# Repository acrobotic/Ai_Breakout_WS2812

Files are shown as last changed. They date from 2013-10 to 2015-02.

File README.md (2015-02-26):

Overview
---
This repository includes the Eagle design files (schematics and layout) for our [WS2812 Breakout Board][1]. The WS2812 is a 
Smart RGB LED with an embedded LED driver (WS2811) that needs only one data input line for controlling brightness and color. 
It represents the most compact solution for adding an RGB LED to a Microcontroller-powered project.

Example firmware files are included in this repository as well.

Product page
---
Please consider buying products from Acrobotic to help fund future Open-Source projects like this! We'll always put our best effort in every project, and release all our design files and code for you to use.

[Tutorials, technical details, and more information about this product can be found here: http://acrobotic.com/catalog/product/view/id/44][1]

License Information
---

All contents of this repository are licensed under a [Creative Commons Attribution-ShareAlike 3.0 Unported License](http://creativecommons.org/licenses/by-sa/3.0/).



[1]: http://acrobotic.com/catalog/product/view/id/44 "WS2812 Breakout Board"

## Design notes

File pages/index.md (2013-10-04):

---
layout: page
title: Ai Breakout WS2812
tagline: Board design files and example firmware for a WS2812 breakout board.
github_project: Ai_Breakout_WS2812
github_user_url: https://github.com/acrobotic
---
{% include JB/setup %}
{% include INCLUDE.md %}

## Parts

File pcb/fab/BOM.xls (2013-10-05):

Ai Breakout WS2812 – BOM
Cisco Zabala (x1sc0@acrobotic.com) last updated: 05.10.2013
Manufacturer | Manuf. Part Number | Vendor | Vendor Part Number | Type | Designator | Qty | Description | Case | SMD, BGA, LCC, OR TH | Notes
TDK |  | Digi-Key | 445-1324-1-ND | Capacitors | C1 | 1 | CAP CER 0.1UF 50V Y5V 0603 | 0603 | SMD
WorldSemi | WS2812 | Acrobotic | LED-00003 | LEDs | RGB | 1 | Intelligent control LED | SMD | SMD

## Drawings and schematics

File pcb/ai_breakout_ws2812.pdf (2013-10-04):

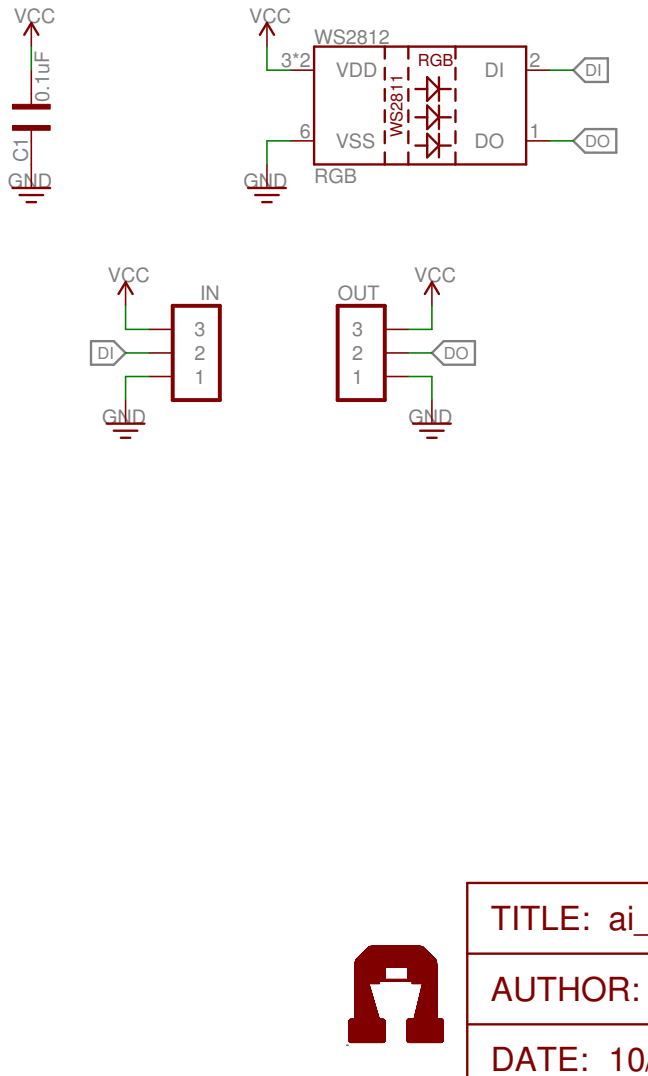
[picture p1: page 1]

AUTHOR: A.I. HARDWARE SITH LORDS | REV: 1.1
DATE: 10/4/13 1:54 PM | SHEET: 1/1

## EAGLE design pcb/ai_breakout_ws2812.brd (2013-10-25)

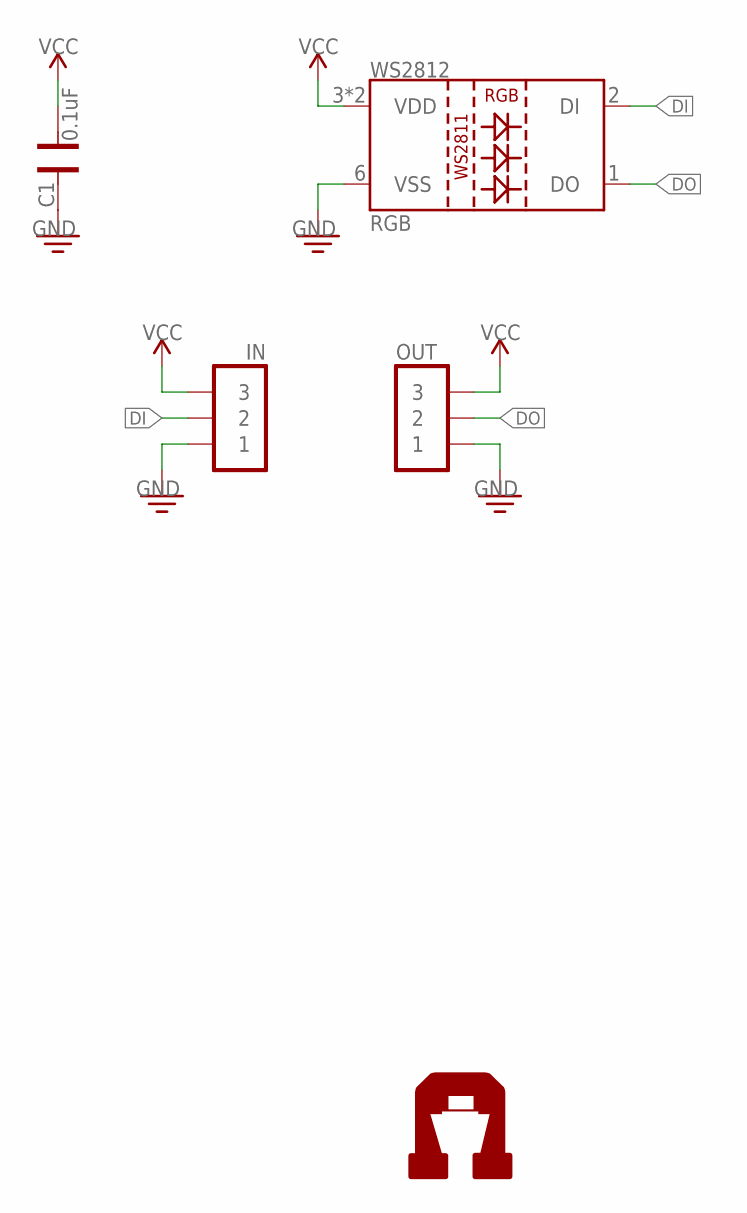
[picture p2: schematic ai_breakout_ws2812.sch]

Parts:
C1: 0.1uF; CAP-0603
IN: 1X03
OUT: 1X03
RGB: LED-WS2812
U$5: AI-LOGOL; AI-LOGO-L

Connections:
DI: IN.2, RGB.2 (DI)
DO: OUT.2, RGB.1 (DO)
GND: C1.2, IN.1, OUT.1, RGB.6 (VSS)
VCC: C1.1, IN.3, OUT.3, RGB.3 (VDD), RGB.5 (VDD)

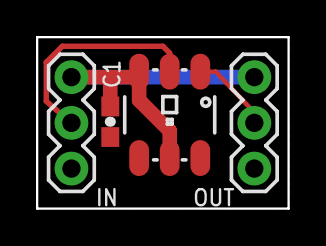
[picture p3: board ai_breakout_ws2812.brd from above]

Board: 2 copper layers, 14.0 x 9.5 mm, 5 parts (1 on the bottom side), 4 nets.

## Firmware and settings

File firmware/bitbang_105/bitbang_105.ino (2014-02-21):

/*------------------------------------------------------------------------
  Acrobotic - 01/10/2013
  Author: x1sc0 
  Platforms: Arduino Uno R3
  File: bitbang_105.ino

  Description: 
  This code sample accompanies the "How To Control 'Smart' RGB LEDs: 
  WS2811, WS2812, and WS2812B (Bitbanging Tutorial)" Instructable 
  () 
  
  The code illustrates how to continuously send a single 105 value to the 
  WS2811 (driver)/WS2812/WS2812B RGB LEDs over a self-clocked 800KHz, NZR 
  signal.  The implementation was done using assembly so that the timing 
  of the signal was extremely accurate.

  Usage:
  Connect power (5V), ground (GND), and the Arduino Uno pin defined 
  by DIGITAL_PIN to the WS281X ports VCC, GND, and DIN ports, respectively.

  Upload the program to an Arduino Uno, and the Green LED of the first 
  WS281X will light up to full brightness. 

  ------------------------------------------------------------------------
  For a full-blown Arduino library, check out:
  https://github.com/acrobotic/Ai_Library_WS281X/
  ------------------------------------------------------------------------
  Please consider buying products from Acrobotic to help fund future
  Open-Source projects like this! We’ll always put our best effort in every
  project, and release all our design files and code for you to use. 
  http://acrobotic.com/
  ------------------------------------------------------------------------

  License:
  Beerware License; if you find the code useful, and we happen to cross 
  paths, you're encouraged to buy us a beer. The code is distributed hoping
  that you in fact find it useful, but  without warranty of any kind.
------------------------------------------------------------------------*/
#define DIGITAL_PIN       6       // Pin connected to the WS281X
#define PORT              PORTB   // Port
#define PORT_PIN          PORTB0

uint32_t t_f;

void setup() 
{
  // Setting DIGITAL_PIN to output, and initializing it to a LOW value
  pinMode(DIGITAL_PIN,OUTPUT);
  digitalWrite(DIGITAL_PIN,0);
}

void loop() 
{
  // Send the bits, and wait 10ms between transmissions.
  bitbang_105();
  delay(10); // This delay is aditional to the 50us needed by the WS281X
             // to latch the data to its output register.  The 50us delay
             // resides inside the function bitbang_255.
}


void bitbang_105(void) 
{
  while((micros() - t_f) < 50L);  // wait for 50us
  //cli(); // Disable interrupts so that timing is as precise as possible

  asm volatile(
  // The volatile attribute is used to tell the compiler not to optimize 
  // this section.  We want every instruction to be left as is.
  //
  // Generating an 800KHz signal (1.25us period) implies that we have
  // exactly 20 instructions clocked at 16MHz (0.0625us duration) to 
  // generate either a 1 or a 0---we need to do it within a single 
  // period. 
  // 
  // By choosing 1 clock cycle as our time unit we can keep track of 
  // the signal's phase (T) after each instruction is executed.
  //
  // To generate a value of 1, we need to hold the signal HIGH (maximum)
  // for 0.8us, and then LOW (minimum) for 0.45us.  Since our timing has a
  // resolution of 0.0625us we can only approximate these values. Luckily, 
  // the WS281X chips were designed to accept a +/- 300ns variance in the 
  // duration of the signal.  Thus, if we hold the signal HIGH for 13 
  // cycles (0.8125us), and LOW for 7 cycles (0.4375us), then the variance 
  // is well within the tolerated range.
  //
  // To generate a value of 0, we need to hold the signal HIGH (maximum)
  // for 0.4us, and then LOW (minimum) for 0.85us.  Thus, holding the
  // signal HIGH for 6 cycles (0.375us), and LOW for 14 cycles (0.875us)
  // will maintain the variance within the tolerated range.
  //
  // For sending a value of 105, we'll need to send the 8 bits:
  // 01101001
  //
  // For a full description of each assembly instruction consult the AVR
  // manual here: http://www.atmel.com/images/doc0856.pdf
    // Instruction        Clock   Description   Phase     Bit Transmitted
    "sbi  %0, %1\n\t"     // 2    PIN HIGH      (T =  2)  
    "rjmp .+0\n\t"        // 2    nop nop       (T =  4)
    "rjmp .+0\n\t"        // 2    nop nop       (T =  6)
    "cbi   %0, %1\n\t"    // 2    PIN LOW       (T =  8)
    "rjmp .+0\n\t"        // 2    nop nop       (T = 10)
    "rjmp .+0\n\t"        // 2    nop nop       (T = 12)
    "rjmp .+0\n\t"        // 2    nop nop       (T = 14)
    "rjmp .+0\n\t"        // 2    nop nop       (T = 16)
    "rjmp .+0\n\t"        // 2    nop nop       (T = 18)
    "rjmp .+0\n\t"        // 2    nop nop       (T = 20)  0
    "sbi  %0, %1\n\t"     // 2    PIN HIGH      (T =  2) 
    "rjmp .+0\n\t"        // 2    nop nop       (T =  4)
    "rjmp .+0\n\t"        // 2    nop nop       (T =  6)
    "rjmp .+0\n\t"        // 2    nop nop       (T =  8)
    "rjmp .+0\n\t"        // 2    nop nop       (T = 10)
    "rjmp .+0\n\t"        // 2    nop nop       (T = 12)
    "nop\n\t"             // 1    nop           (T = 13)
    "cbi   %0, %1\n\t"    // 2    PIN LOW       (T = 15)
    "rjmp .+0\n\t"        // 2    nop nop       (T = 17)
    "rjmp .+0\n\t"        // 2    nop nop       (T = 19)
    "nop\n\t"             // 1    nop           (T = 20)  1
    "sbi  %0, %1\n\t"     // 2    PIN HIGH      (T =  2)
    "rjmp .+0\n\t"        // 2    nop nop       (T =  4)
    "rjmp .+0\n\t"        // 2    nop nop       (T =  6)
    "rjmp .+0\n\t"        // 2    nop nop       (T =  8)
    "rjmp .+0\n\t"        // 2    nop nop       (T = 10)
    "rjmp .+0\n\t"        // 2    nop nop       (T = 12)
    "nop\n\t"             // 1    nop           (T = 13)
    "cbi   %0, %1\n\t"    // 2    PIN LOW       (T = 15)
    "rjmp .+0\n\t"        // 2    nop nop       (T = 17)
    "rjmp .+0\n\t"        // 2    nop nop       (T = 19)
    "nop\n\t"             // 1    nop           (T = 20)  1
    "sbi  %0, %1\n\t"     // 2    PIN HIGH      (T =  2)
    "rjmp .+0\n\t"        // 2    nop nop       (T =  4)
    "rjmp .+0\n\t"        // 2    nop nop       (T =  6)
    "cbi   %0, %1\n\t"    // 2    PIN LOW       (T =  8)
    "rjmp .+0\n\t"        // 2    nop nop       (T = 10)
    "rjmp .+0\n\t"        // 2    nop nop       (T = 12)
    "rjmp .+0\n\t"        // 2    nop nop       (T = 14)
    "rjmp .+0\n\t"        // 2    nop nop       (T = 16)
    "rjmp .+0\n\t"        // 2    nop nop       (T = 18)
    "rjmp .+0\n\t"        // 2    nop nop       (T = 20)  0
    "sbi  %0, %1\n\t"     // 2    PIN HIGH      (T =  2)
    "rjmp .+0\n\t"        // 2    nop nop       (T =  4)
    "rjmp .+0\n\t"        // 2    nop nop       (T =  6)
    "rjmp .+0\n\t"        // 2    nop nop       (T =  8)
    "rjmp .+0\n\t"        // 2    nop nop       (T = 10)
    "rjmp .+0\n\t"        // 2    nop nop       (T = 12)
    "nop\n\t"             // 1    nop           (T = 13)
    "cbi   %0, %1\n\t"    // 2    PIN LOW       (T = 15)
    "rjmp .+0\n\t"        // 2    nop nop       (T = 17)
    "rjmp .+0\n\t"        // 2    nop nop       (T = 19)
    "nop\n\t"             // 1    nop           (T = 20)  1
    "sbi  %0, %1\n\t"     // 2    PIN HIGH      (T =  2)
    "rjmp .+0\n\t"        // 2    nop nop       (T =  4)
    "rjmp .+0\n\t"        // 2    nop nop       (T =  6)
    "cbi   %0, %1\n\t"    // 2    PIN LOW       (T =  8)
    "rjmp .+0\n\t"        // 2    nop nop       (T = 10)
    "rjmp .+0\n\t"        // 2    nop nop       (T = 12)
    "rjmp .+0\n\t"        // 2    nop nop       (T = 14)
    "rjmp .+0\n\t"        // 2    nop nop       (T = 16)
    "rjmp .+0\n\t"        // 2    nop nop       (T = 18)
    "rjmp .+0\n\t"        // 2    nop nop       (T = 20)  0
    "sbi  %0, %1\n\t"     // 2    PIN HIGH      (T =  2)
    "rjmp .+0\n\t"        // 2    nop nop       (T =  4)
    "rjmp .+0\n\t"        // 2    nop nop       (T =  6)
    "cbi   %0, %1\n\t"    // 2    PIN LOW       (T =  8)
    "rjmp .+0\n\t"        // 2    nop nop       (T = 10)
    "rjmp .+0\n\t"        // 2    nop nop       (T = 12)
    "rjmp .+0\n\t"        // 2    nop nop       (T = 14)
    "rjmp .+0\n\t"        // 2    nop nop       (T = 16)
    "rjmp .+0\n\t"        // 2    nop nop       (T = 18)
    "rjmp .+0\n\t"        // 2    nop nop       (T = 20)  0
    "sbi  %0, %1\n\t"     // 2    PIN HIGH      (T =  2)
    "rjmp .+0\n\t"        // 2    nop nop       (T =  4)
    "rjmp .+0\n\t"        // 2    nop nop       (T =  6)
    "rjmp .+0\n\t"        // 2    nop nop       (T =  8)
    "rjmp .+0\n\t"        // 2    nop nop       (T = 10)
    "rjmp .+0\n\t"        // 2    nop nop       (T = 12)
    "nop\n\t"             // 1    nop           (T = 13)
    "cbi   %0, %1\n\t"    // 2    PIN LOW       (T = 15)
    "rjmp .+0\n\t"        // 2    nop nop       (T = 17)
    "rjmp .+0\n\t"        // 2    nop nop       (T = 19)
    "nop\n\t"             // 1    nop           (T = 20)  1
    ::
    // Input operands
    "I" (_SFR_IO_ADDR(PORT)), //%0
    "I" (PORT_PIN)            //%1
  );
  sei();                          // Enable interrupts
  t_f = micros();                 // t_f will be used to measure the 50us 
                                  // latching period in the next call of the 
                                  // function.
}

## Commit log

2013-09-18 Modified silkscreen on the board.
    [ai_breakout_ws2812.brd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]
2013-09-29 Corrected silkscreen widths, BOM, searchable PDF schematic.
    [BOM.xls, DRILEGEND.CFG, ai_breakout_ws2812.brd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]
2013-09-29 Deleted unwanted files.
    [DRILEGEND.CFG]
2013-10-04 Minor modifications. Version is now 1.1.
    [ai_breakout_ws2812.brd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]
2013-10-04 Minor mod to BOM.xls
    [BOM.xls]
2013-10-04 Updated pdf version of schematic
    [ai_breakout_ws2812.sch]
2013-10-04 updating schematic pdf (non-vector font)
2013-10-05 Minor formatting change of BOM.
    [BOM.xls]
2013-10-25 Centered pins.
    [ai_breakout_ws2812.brd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]
